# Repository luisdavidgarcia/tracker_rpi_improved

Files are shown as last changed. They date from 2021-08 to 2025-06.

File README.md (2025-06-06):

# Online Data Collection Module for PyMouseTracks (Raspberry Pi recording module)

# NOTE: I noticed there were issues with the original setup of the project, so 
I have updated the setup script to now create a python 
virtual enviroment and install all the dependencies there from 
a `requirements.txt` file.

To clone the repository, run the following in terminal. The recursive tag is required for the RFIDTagReader submodule to work correctly.
```
git clone --recursive https://github.com/tf4ong/tracker_rpi.git
```
To install the setup script by running in the cloned folder

```
chmod 777 setup.sh
./setup.sh
```
To run the tracker cage, enter the command in the cloned folder
```
python3 main2.py
```

For full video tutorial on setting up the software and editing recording settings, please refer to this [link](https://youtu.be/E22OtdMjgwc)

To setup a Raspberry Pi, please refer to the following links

[Official Raspberry Pi Tutorial](https://www.youtube.com/watch?v=wjWZhV1v3Pk)

[Tom's Hardware](https://www.tomshardware.com/reviews/raspberry-pi-set-up-how-to,6029.html)

# Basic Concept and Essential Hardware
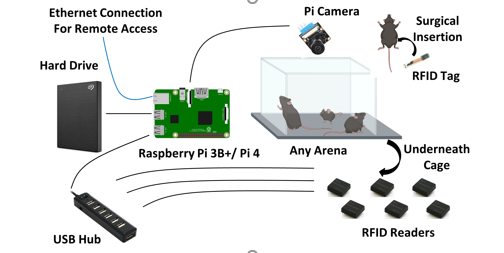
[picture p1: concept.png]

- Any Pi compatible camera can be used as long as there is an over headview of all mice
- Timestamp of each frame is written to a csv file
- RFID readings and their corresponding timestamps are also written in a csv file
- Most of the hardware can readily purchased on distributing sites such as [Amazon](https://www.amazon.ca/ref=nav_logo)

### RFID System
- To identify and validate mice 
- ID-20LA RFID tag readers setup at the custome locations at the bottom of the cage
- Locations of the readers must be sparse enough to minimize electromagnetic interference (approx 12cm)
- [RFID reader details](https://www.sparkfun.com/products/11828)
- [RFID reader base details](https://www.sparkfun.com/products/9963)
- RFID tag reader module developed by [Jamie Boyd](https://github.com/jamieboyd/RFIDTagReader)
- Aprroximate cost for each reader is 86 CAD
- [Tags](https://www.sparkfun.com/products/9416) cost about 6 CAD and can be reused after cleaning with solutions like ethanol

# FPS at Different Resolutions on Pi3/4 
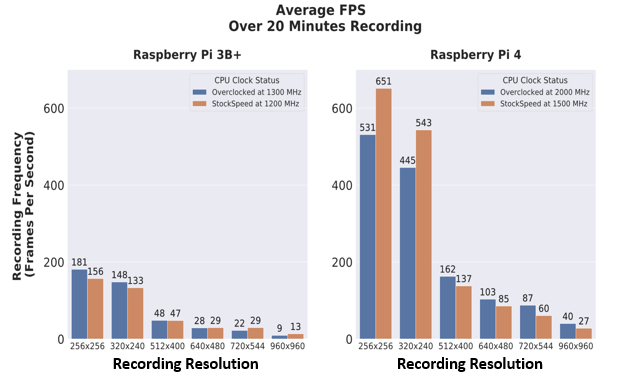
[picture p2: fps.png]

- can be record up to 40 fps at 960 x960 on a Raspiberry Pi 4

# Recording Rodents in Various Settings

## Traditional Open-Field/Three Chamber
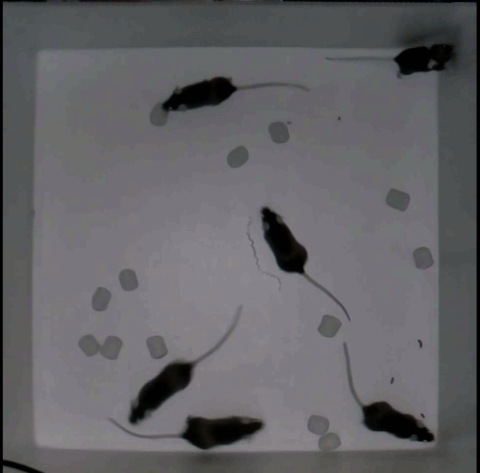
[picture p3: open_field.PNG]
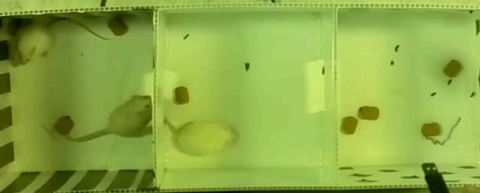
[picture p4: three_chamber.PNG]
 | 

## Custom Home-cage Setups
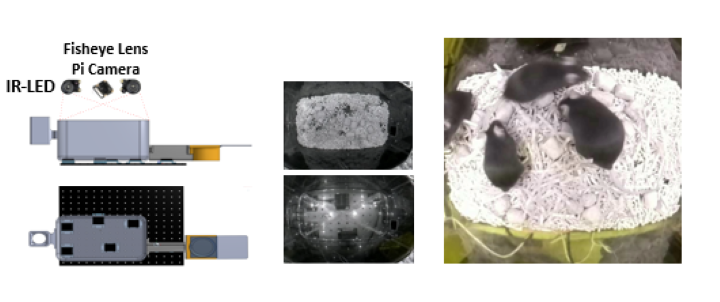
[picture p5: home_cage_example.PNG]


# PRT Analysis Analysis
- Fully python based
- Yolov4 Detection and SORT tracking
- RFID matching methods based on Pandas framework
- More information can be found on the following [github link](https://github.com/tf4ong/PyRodentTracks)
- To ensure efficient processing speeds in the offline analysis, it is recommended that each recording do not exceede 12 hours.
- If longer recordings are needed, a simple restart will be best
- Sample video can be found at [Youtube](https://youtube.com/playlist?list=PLmcjDqLt_Xk6AAlll3ztvgNI9P3yQxPc2)

Simple Open Field Build [tutorial](https://youtu.be/2uP5MmRD7ns)

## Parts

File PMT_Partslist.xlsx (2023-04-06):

Component | Amount Required | Supplier | Part Number | Notes
Raspberry Pi 3B/4 | 1 | Newark | RASPBERRYPI3-MODB-1GB/RASPBERRYPI4-MODB-4GB | Either model could be used
RFID Reader ID20-LA | Depends on user | Sparkfun | SEN-11828 | As many as the user wants as long as there are spaced a minimum of 12 cm apart
RFID Reader Breakout | Depends on user | Sparkfun | SEN-09963 | Matching to the number of RFID Reader ID20-LA
USB Mini B Cable | Depends on user | AmazonBasics | N/A | Or equivalent.
RFID Glass Capsules | 1 | Sparkfun | SEN-09416 | One needed per animal to be tested.
16GB Micro-SD Card | 1 | Scan | 44082 | Or equivalent.
Pi Camera(F/G) | 1 | Waveshare | 10299/10344 | Or any other Pi compatible camera
Portable Hard Drive | 1 | Seagate | STKC4000400 | Or equivalent.
RPi Cooler | 1 | Smraza | SW49 | Optional but recommended. Other equivalent options could be used
Thermal Paste | 1 | Noctua | NT-H1 | Optional but recommended. Other equivalent options could be used
PLA Filament, 1.75mm Black | Depends on user | MakerBot | MP05775 | Optional. To print custom 3D parts for home-cage design or RFID reader holder. Other equivalent options could be used

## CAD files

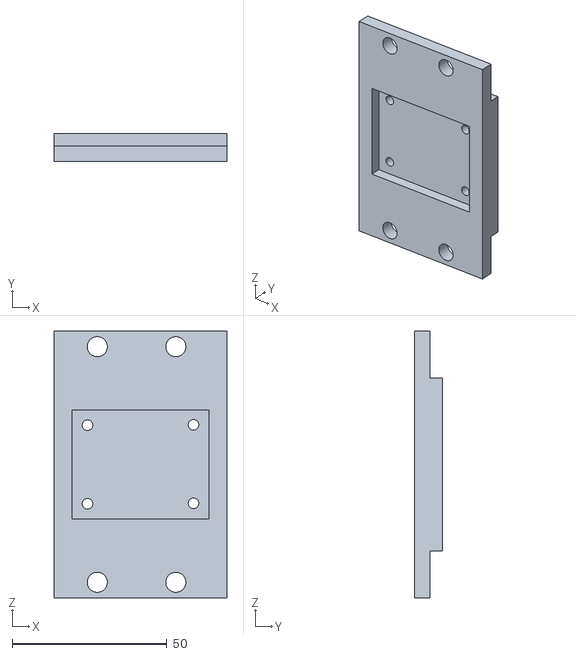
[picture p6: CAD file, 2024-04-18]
stl_files/Reader Base.STL
55.9 x 9.00 x 86.4

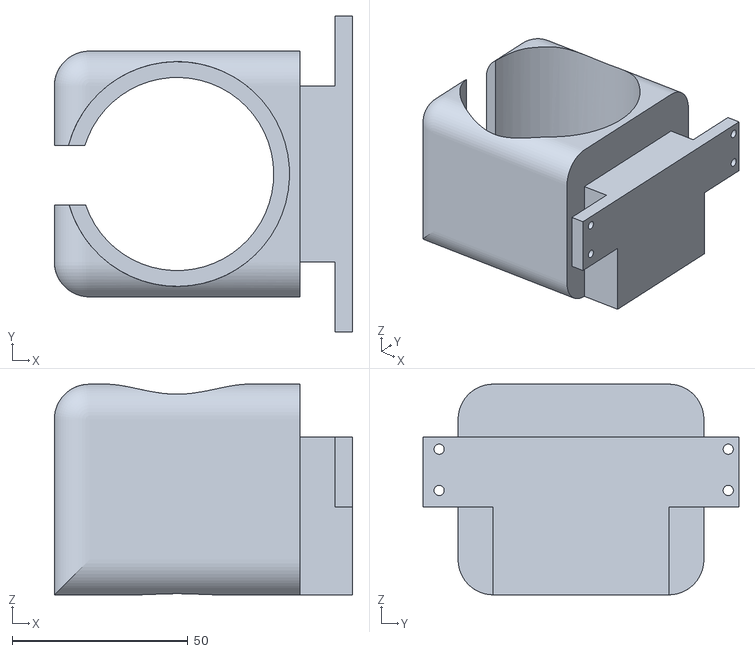
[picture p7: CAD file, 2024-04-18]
stl_files/Water_Bottle_holder.stl
85.0 x 90.0 x 60.0

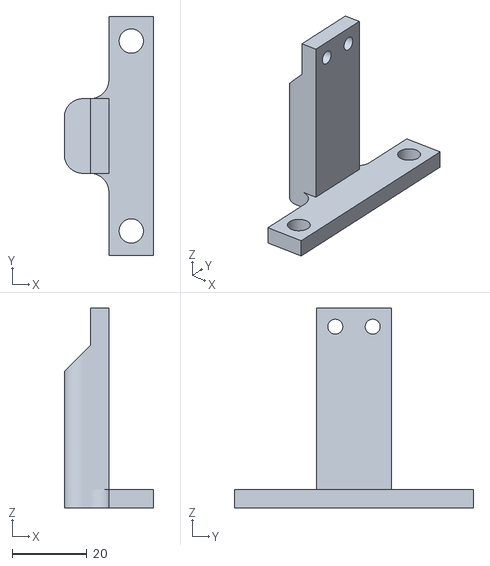
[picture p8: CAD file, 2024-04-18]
stl_files/Cage Base Attachment.stl
23.9 x 64.0 x 53.5

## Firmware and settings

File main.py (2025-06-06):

from time import time, sleep
from datetime import datetime
from udp_socket import rpi_socket
from settings_loader import camera_settings, pi_settings
from pts_picamera import pts_picam
import multiprocessing
import os



class rpi_recorder():
    """:class: 'rpi_recorder' is the top level class of natural mouse tracker. It creates :class: 'RFID_reader' objects
    which run in separate threads, and also runs camera recording in the main loop. User config files can be found in 
    'config.ini'
    """

    def __init__(self):
        """Constructor for :class: 'recorder'. Loads the config file 'config.ini' and creates a :class:'pi_video_stream' 
        object and four :class:'RFID_reader' objects.
        """
        # Load settings
        self.pi_settings = pi_settings('config.ini')
        self.camera_settings = camera_settings('config.ini')
    
    def setup(self):
        tm = datetime.now().strftime('%Y-%m-%d_%H-%M-%S') 
        self.data_path = self.pi_settings['data_path'] + '/'+ tm
        os.mkdir(self.data_path) 
        #setup camera
        self.camera = pts_picam(self.camera_settings,self.pi_settings)
        self.camera.setup()
        # Making directory
      
        # thread setup for RFID reading

        if self.pi_settings['spt']:
            self.spt_socket=rpi_socket(self.pi_settings['ip'], self.pi_settings['port'],self.data_path+'/spt_text.csv')

    def run(self):
        """Main function that opens threads and runs :class: 'pi_video_stream' in main thread. In each thread,
         :class:'RFID_reader' checks for RFID pickup. The pickup data is then logged to a text file 
         by :class: 'pi_video_stream'.
        """
        # start threads and multiprocess
        if self.pi_settings['rfid']:
            readers=["self.reader{}=RFID_reader('/dev/ttyUSB{}', '{}',self.data_path+'/RFID_reads.csv')".format(i,i,i)\
                 for i in range(self.pi_settings['nreaders'])]
            for i in readers:
                exec(i)
        if self.pi_settings['rfid']:
            reader_process=["t_rfid{}=Thread(target=self.reader{}.scan,daemon=True)".format(i,i) \
                for i in range(self.pi_settings['nreaders'])]
            for i in reader_process:
                exec(i) 
        if self.pi_settings['rfid']=='True':
            s_rfid=multiprocessing.Process(target=self.spt_socket.run, daemon=True)
        # Start Processes
        if self.pi_settings['rfid']:
            reader_startup=["t_rfid{}.start()".format(i) for i in range(self.pi_settings['nreaders'])]
            for i in reader_startup:
                exec(i)
        if self.pi_settings['spt']:
            s_rfid.start()
        self.camera.record()
        if self.pi_settings['user_interrupt_only']:
            start_time = time()
            while True:
                try:
                    sleep(0.0001)
                except KeyboardInterrupt:
                    self.camera.stop_recording()
        else:
            start_time = time()
            end_time = start_time + self.pi_settings['duration']
            current_time = time()
            while current_time <= end_time:
                try:
                    current_time = time()
                except KeyboardInterrupt:
                    break
            self.camera.camera.stop_recording()
        dur = time() - start_time  
        print(f' Recorded for {dur} seconds ')
        print("Finished recording at "+str(datetime.now()))


if __name__ == "__main__":
     rc = rpi_recorder()
     rc.setup()
     rc.run()
     print("Finished recording at "+str(datetime.now()))

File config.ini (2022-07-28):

[camera]
resolution = 960, 960
framerate = 40
Display = True
shutter_speed = 7812
iso = 800
sensor_mode = 0 
awb_mode = auto
exposure_mode = auto 
awb_gains = 1,1
horizontal_flip = True
vertical_flip = True



[pi]
data_root = /media/pi/40263589263580C8/rpi_test/
user_interrupt_only = True
duration = 600
rfid= True
nreaders=9
spt= False
port= 2555
ip=142.103.107.225

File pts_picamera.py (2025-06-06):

import io
from picamera import PiCamera
import time
from time import time, sleep
from datetime import datetime

'''
post:https://forums.raspberrypi.com/viewtopic.php?t=106930
Not really software/hardware engineer but the timestamps work!
'''

class PtsOutput(object):
    def __init__(self, camera, video_filename, pts_filename):
        self.camera = camera
        self.video_output = io.open(video_filename, 'wb')
        self.pts_output = io.open(pts_filename, 'w')
        self.start_time = None
        self.frame_count = 0
        self.pts_output.write(f'StartTime: {time()}\n')
        self.pts_output.write('frame,Timestamp\n') # reference start timestamp

    def write(self, buf):
        self.video_output.write(buf)
        if self.camera.frame.complete and self.camera.frame.timestamp:
            self.pts_output.write(f'{self.frame_count},{self.camera.frame.timestamp}\n') # get stc timestamp, more accurate 
            self.frame_count +=1
    
    def flush(self):	
        self.video_output.flush()
        self.pts_output.flush()
        
    def close(self):
        self.video_output.close()
        self.pts_output.close()	

'''
slight addition to picamera library for path saves and timestamps
'''

class pts_picam():
    def __init__(self,camera_settings,pi_settings):
        self.pi_settings = pi_settings
        self.camera_settings = camera_settings
        data_path=pi_settings['data_path']
        tm = datetime.now().strftime('%Y-%m-%d_%H-%M-%S')
        self.data_path = data_path + tm + '/'

    def setup(self):
        self.camera = PiCamera()
        self.camera.resolution = self.camera_settings['resolution']
        self.camera.shutter_speed= self.camera_settings['shutter_speed']
        self.camera.framerate = self.camera_settings['framerate']
        sleep(0.2)
        self.camera.awb_mode = self.camera_settings['awb_mode']
        self.camera.iso = self.camera_settings['iso']
        self.camera.sensor_mode = self.camera_settings['sensor_mode']
        self.camera.awb_gains = self.camera_settings['awb_gains']
        self.camera.exposure_mode = self.camera_settings['exposure_mode']
        self.camera.vflip = self.camera_settings['vertical_flip']
        self.camera.hflip = self.camera_settings['horizontal_flip']
        sleep(0.2)
        print("FINAL Analog gains:  ", float(self.camera.analog_gain))
        print("FINAL Digital gains: ", float(self.camera.digital_gain))
        print("FINAL Shutter speed: ", self.camera.shutter_speed)
        print("FINAL ISO: ",self.camera.iso)
        print("FINAL Auto White Balance Gains: ",self.camera.awb_gains)
        print("Exposure Mode: ", self.camera.exposure_mode)
        print("Auto White Balance Mode: ",self.camera.awb_mode) 

    def record(self):
        pts_path= self.data_path+'timestamps.csv'
        file_path = self.data_path+'behavior.h264'
        print(file_path)
        self.camera.start_recording(PtsOutput(self.camera, file_path, pts_path), format='h264' ,level='4.2')
        if self.camera_settings['Display']:
            self.camera.start_preview(fullscreen=False, \
                window=((10, 10, 256, 256)))

    def stop_record(self):
        if self.camera_settings['Display'] == 'True':
            self.camera.stop_preview()
        self.camera.stop_recording()
        self.camera.close()

'''
#demo code
camera = PiCamera()
camera.resolution = (960,960)
#c
camera.framerate = 90
#camera.awb_mode = 'off'
#camera.awb_gains = (1,1)
file_path='/media/pi/Seagate Expansion Drive/New/test.h264'
pts_path='/media/pi/Seagate Expansion Drive/New/test.txt'
camera.start_recording(PtsOutput(camera, file_path, pts_path), format='h264' ,level='4.2')
camera.start_preview(fullscreen=False, window=((10, 10, 640, 480)))
while True:
    try:
        sleep(0.1)
    except KeyboardInterrupt:
        camera.stop_recording()
        break
'''

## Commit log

2021-02-19 Added Display and adjust framerate options
2021-02-22 fixed some huger frame drop issues
    [config.ini, main_2.py]
2021-11-04 streams video at picamera framerate
2021-11-05 fix duplicate frames
2022-07-28 fixed minor user issues
    [main.py]
